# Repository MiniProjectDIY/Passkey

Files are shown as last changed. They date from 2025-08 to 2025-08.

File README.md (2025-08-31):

# Passkey
use your finterprint to send password via virtual keyboard

# ME
Moduleholder: using screw pillar M2\*4*1.5+2.5\*1, M2\*7 screws

Passkey Case: using 4xM2(screw diameter)\*3(Length)\*3.5(outter diameter) screw inserts,M2\*8 screws

# SW
using project:passkey_tune_and_set to :

1.get module sn

2.register your finterprint

3.change module address(do this at last)

using python project PassKey_utils to encrypt your password with your module sn

using project passkey_final_run to run as final code,

remember to change the module address,the macro define and the encrypted password per your own condition.

# HW
using folder production for PCB/SMT process,or handsolder by yourself.


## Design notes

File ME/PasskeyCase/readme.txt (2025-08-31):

using 4*M2(screw diameter)*3(Length)*3.5(outter diameter) screw inserts

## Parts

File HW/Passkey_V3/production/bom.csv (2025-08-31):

Designator | Footprint | Quantity | Value | LCSC Part #
C1, C10, C19, C20, C6, C9 | 0402 | 6 | C_0402_2.2uF_6.3V_X5R
C11, C12, C14, C15, C18, C8 | 0402 | 6 | C_0402_100nF_10V_X7R
C13, C16 | 0402 | 2 | C_0402_15pF_50V_C0G
C17, C2, C5 | 0402 | 3 | C_0402_4.7uF_10V_X5R
C3 | 0402 | 1 | C_0402_1uF_10V_X5R
C7 | 0402 | 1 | C_0402_22nF_50V_X7R
CN1 | CONN-SMD_6P-P1.00_XUNPU_WAFER-SH1.0-6PWB | 1 | WAFER-SH1_0-6PWB | C3029345
D1, D2 | 0402 | 2 | TPESD0402G05V
D3 | 0603 | 1 | NCD0603G1
F1 | 0402 | 1 | BSMD0402L-020
J2 | USB_C_Receptacle_G-Switch_GT-USB-7010ASV | 1 | GT-USB-7010ASV
R10, R11 | 0402 | 2 | R_0402_5.1K_5%
R2, R3 | 0402 | 2 | R_0402_27_5%
R4 | 0402 | 1 | R_0402_200_5%
R5, R6 | 0402 | 2 | R_0402_1K_5%
R7 | 0402 | 1 | R_0402_470_5%
R8, R9 | 0402 | 2 | R_0402_0_5%
SW1 | SW_SPST_B3U-1000P | 1 | B3U-1000P
U1 | USON8-2x3mm-EP0.2x1.6mm | 1 | W25Q16JVUXIQ
U2 | ZW101 | 1 | ~
U4 | QFN-56-1EP_7x7mm_P0.4mm_EP3.2x3.2mm | 1 | RP2040
U5 | SOT-23 | 1 | 662K
Y1 | Crystal_SMD_2520-4Pin_2.5x2.0mm | 1 | X252012MMB4SI-24

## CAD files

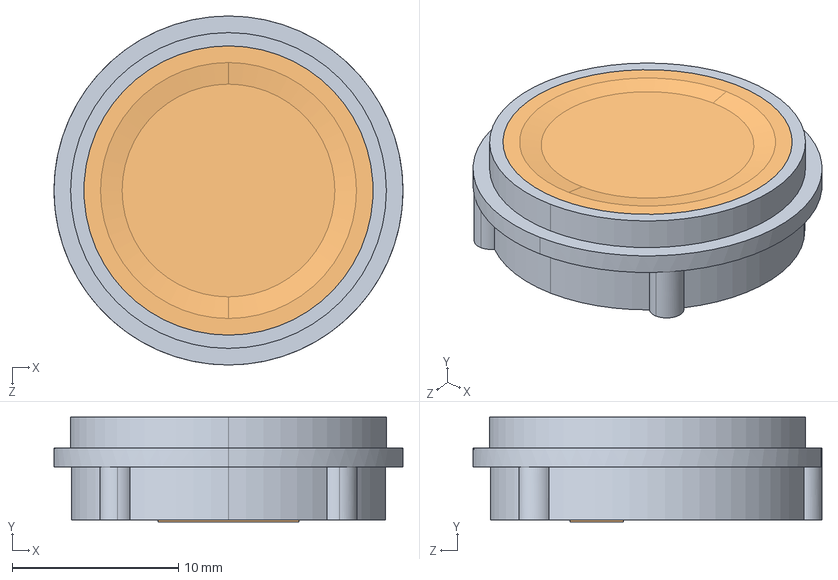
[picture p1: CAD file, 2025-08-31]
Datasheet/ZW101.STEP
21.0 x 6.30 x 21.0 mm
半导体指纹模组外壳
CP-6852 PCB

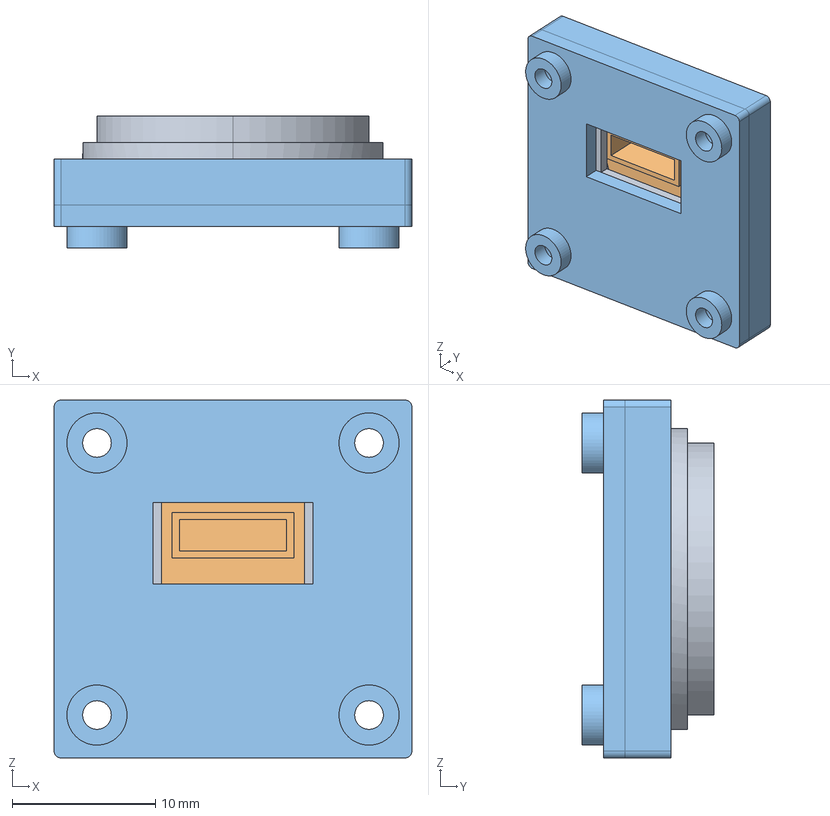
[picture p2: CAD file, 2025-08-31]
ME/ModuleHolder/ZW101_w_holder.step
25.0 x 9.20 x 25.0 mm
mod
CP-6852 PCB
HolderWStub

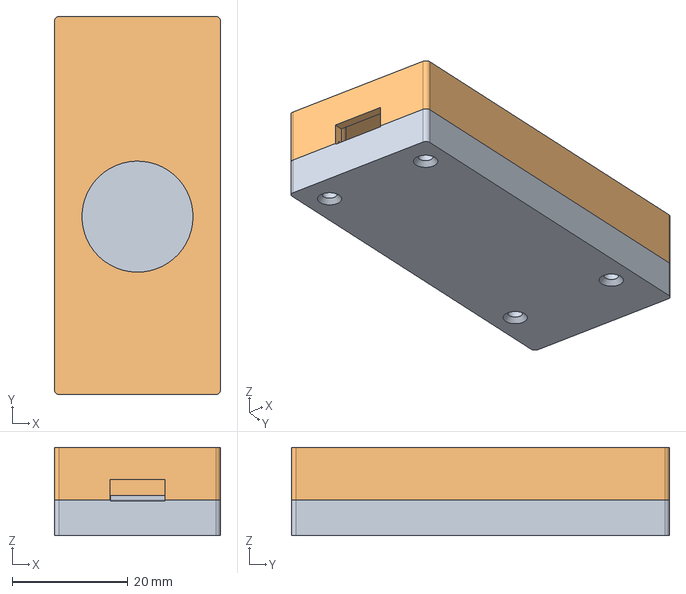
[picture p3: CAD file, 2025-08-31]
ME/PasskeyCase/passkey_v3_case.FCStd
28.7 x 65.3 x 15.3 mm
Bottom
Lid

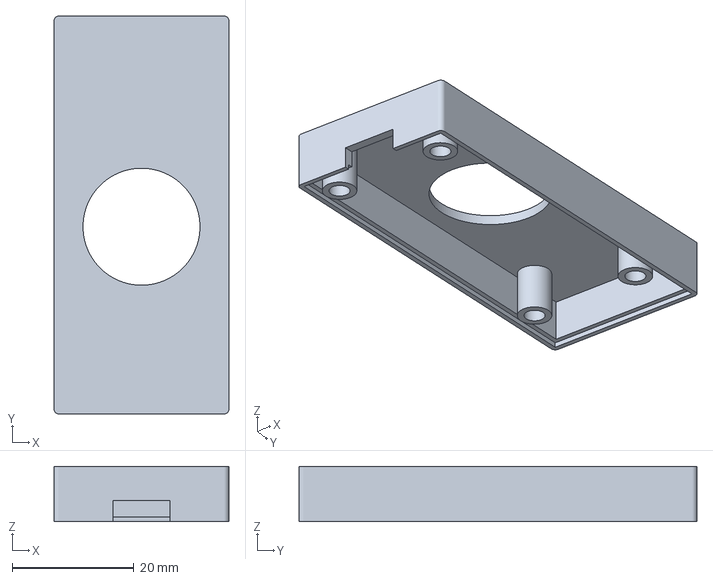
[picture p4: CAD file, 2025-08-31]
ME/PasskeyCase/passkey_v3_case-Lid.3mf
28.7 x 65.3 x 9.10 mm

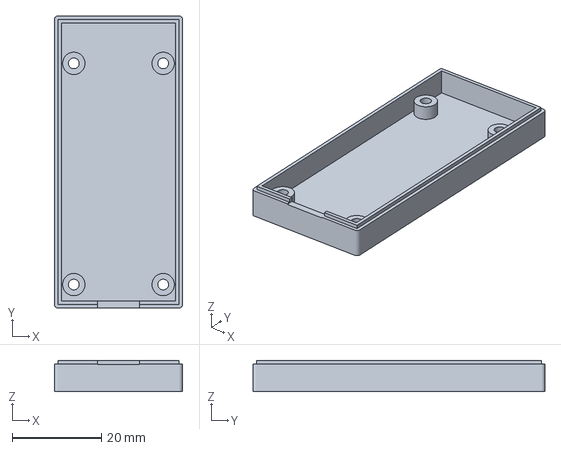
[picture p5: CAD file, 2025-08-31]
ME/PasskeyCase/passkey_v3_case-Bottom.3mf
28.7 x 65.3 x 7.00 mm

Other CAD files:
ME/ModuleHolder/module_holder.FCStd
Datasheet/ZW101.DWG
ME/ModuleHolder/module_holder.3mf

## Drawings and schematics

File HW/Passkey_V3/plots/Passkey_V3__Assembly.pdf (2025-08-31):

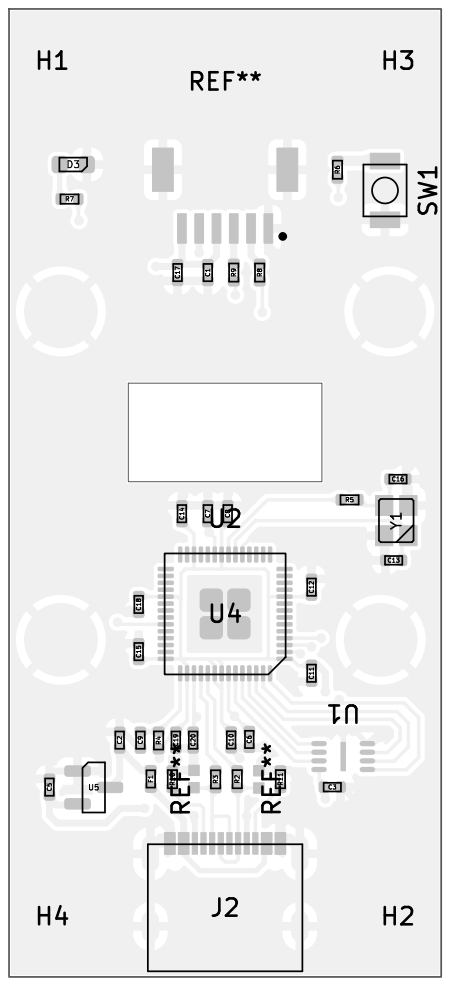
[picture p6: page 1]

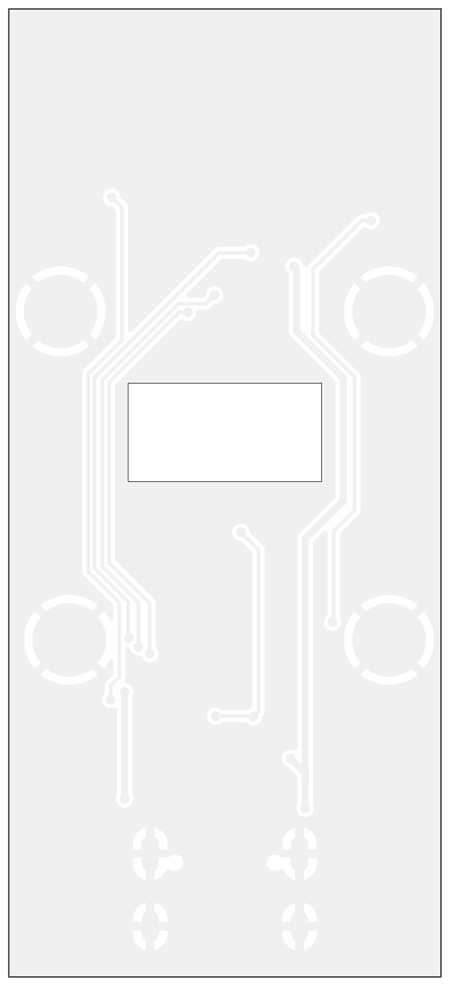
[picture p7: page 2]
D Date: KiCad; E.D.A. 9.0.3 Size: A4; Rev:; Id: /1 Title: File: Passkey_V3.kicad_pcb Sheet: Black; And; White; BOT Board2Pdf:; Black; BOT -; Page 2/2

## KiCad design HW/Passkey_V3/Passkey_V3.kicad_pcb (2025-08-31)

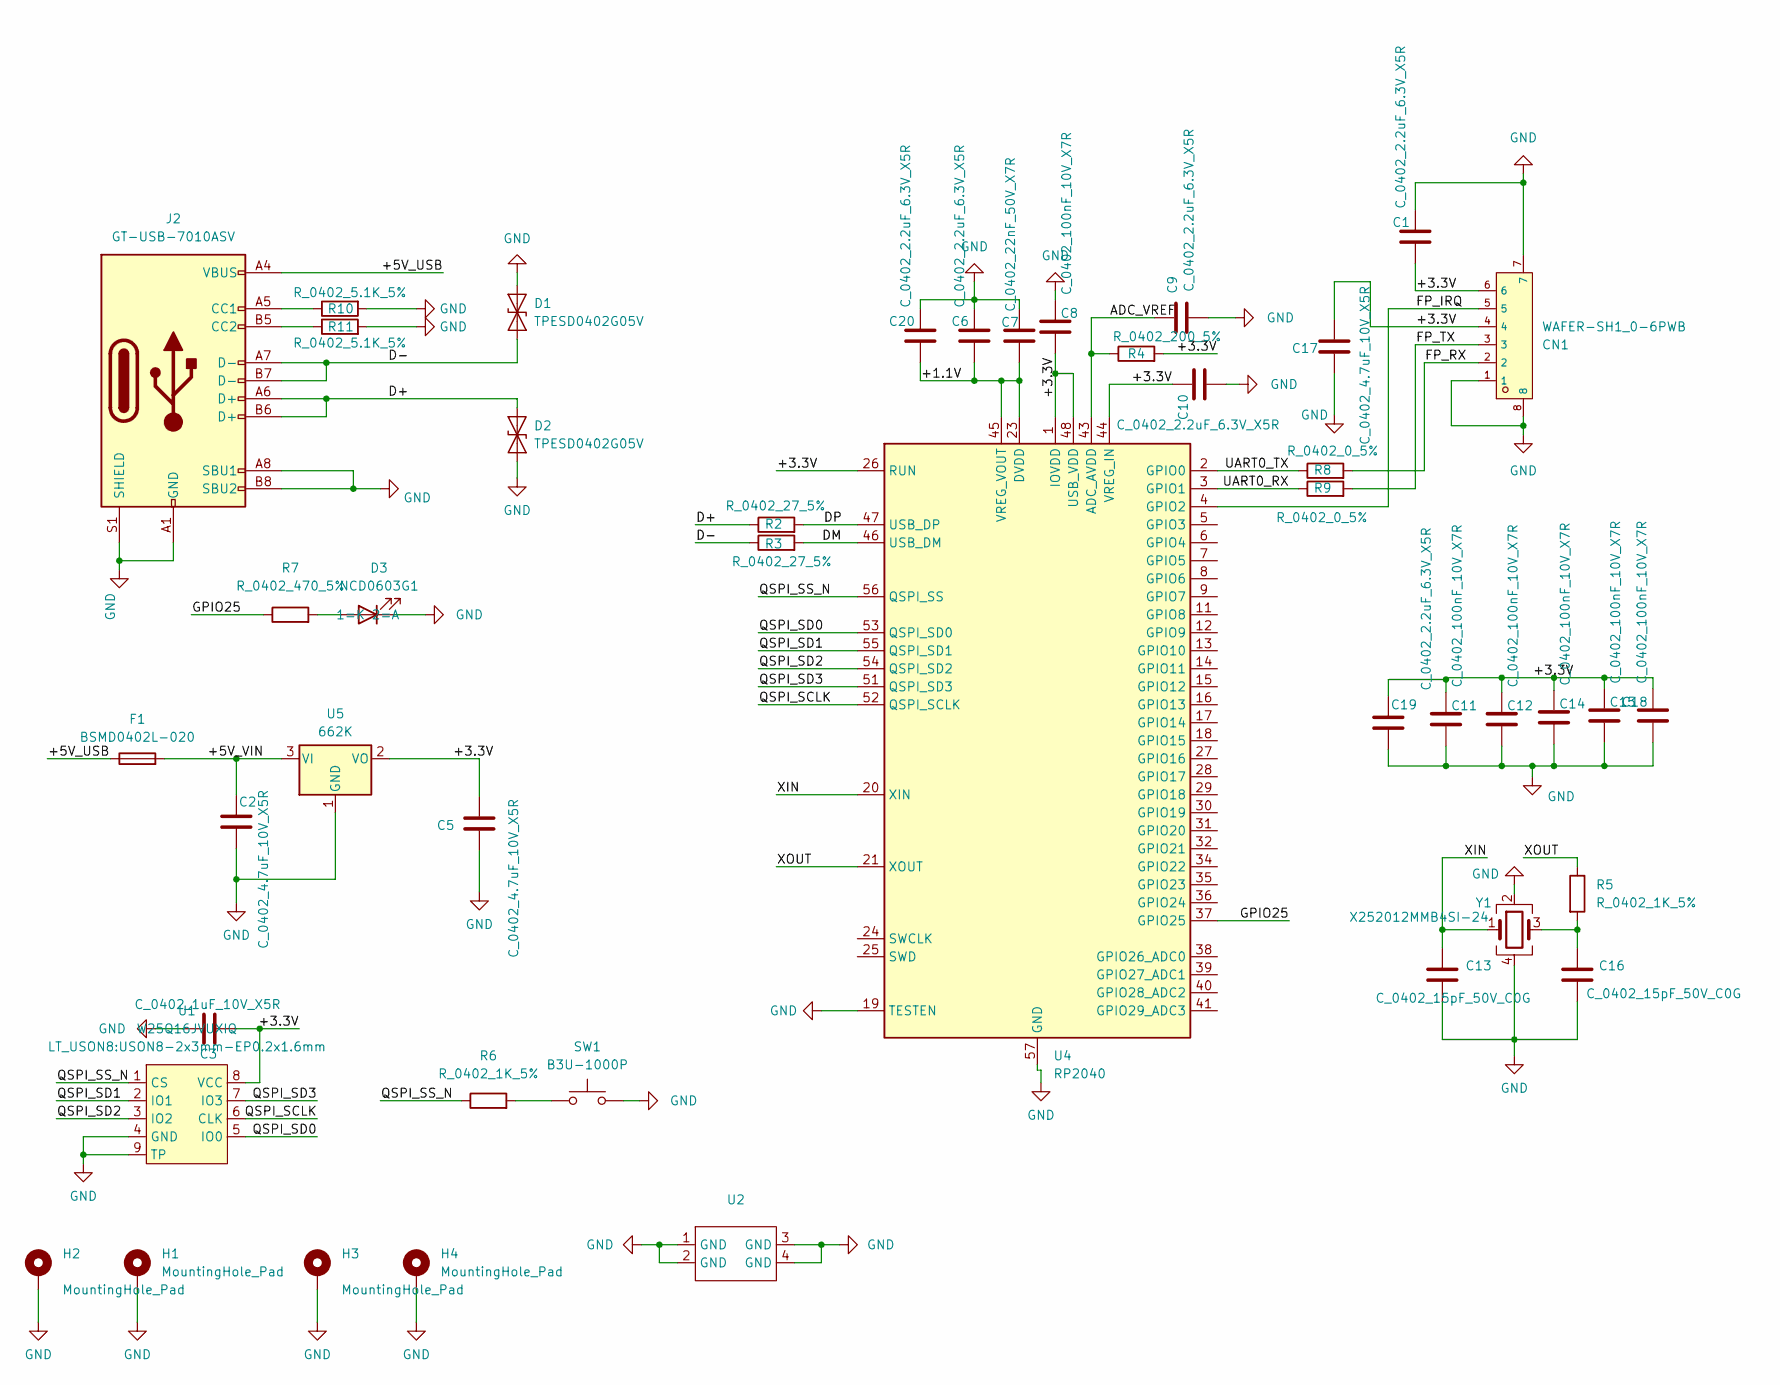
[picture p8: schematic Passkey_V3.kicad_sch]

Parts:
C1, C6, C9, C10, C19, C20: C_0402_2.2uF_6.3V_X5R; C_0402_1005Metric
C2, C5, C17: C_0402_4.7uF_10V_X5R; C_0402_1005Metric
C3: C_0402_1uF_10V_X5R; C_0402_1005Metric
C7: C_0402_22nF_50V_X7R; C_0402_1005Metric
C8, C11, C12, C14, C15, C18: C_0402_100nF_10V_X7R; C_0402_1005Metric
C13, C16: C_0402_15pF_50V_C0G; C_0402_1005Metric
CN1: WAFER-SH1_0-6PWB; CONN-SMD_6P-P1.00_XUNPU_WAFER-SH1.0-6PWB; LCSC C3029345
D1, D2: TPESD0402G05V; D0402-BI
D3: NCD0603G1; LED_0603_1608Metric
F1: BSMD0402L-020; Fuse_0402_1005Metric
H1, H2, H3, H4: MountingHole_Pad; MountingHole_2.2mm_M2_Pad
J2: GT-USB-7010ASV; USB_C_Receptacle_G-Switch_GT-USB-7010ASV
R2, R3: R_0402_27_5%; R_0402_1005Metric
R4: R_0402_200_5%; R_0402_1005Metric
R5, R6: R_0402_1K_5%; R_0402_1005Metric
R7: R_0402_470_5%; R_0402_1005Metric
R8, R9: R_0402_0_5%; R_0402_1005Metric
R10, R11: R_0402_5.1K_5%; R_0402_1005Metric
SW1: B3U-1000P; SW_SPST_B3U-1000P
U1: W25Q16JVUXIQ; USON8-2x3mm-EP0.2x1.6mm
U2: ZW101
U4: RP2040; QFN-56-1EP_7x7mm_P0.4mm_EP3.2x3.2mm
U5: 662K; SOT-23
Y1: X252012MMB4SI-24; Crystal_SMD_2520-4Pin_2.5x2.0mm

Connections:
/+1.1V: C6.2, C7.2, C20.2, U4.23 (DVDD), U4.45 (VREG_VOUT), U4.50 (DVDD)
/+3.3V: C1.2, C3.1, C5.1, C8.2, C10.1, C11.1, C12.1, C14.1, C15.1, C17.1, C18.1, C19.2, CN1.4, CN1.6, R4.2, U1.8 (VCC), U4.1 (IOVDD), U4.10 (IOVDD), U4.22 (IOVDD), U4.26 (RUN), U4.33 (IOVDD), U4.42 (IOVDD), U4.44 (VREG_IN), U4.48 (USB_VDD), U4.49 (IOVDD), U5.2 (VO)
/+5V_USB: F1.1, J2.A4 (VBUS), J2.A9 (VBUS), J2.B4 (VBUS), J2.B9 (VBUS)
/+5V_VIN: C2.1, F1.2, U5.3 (VI)
/ADC_VREF: C9.1, R4.1, U4.43 (ADC_AVDD)
/D+: D2.2 (A2), J2.A6 (D+), J2.B6 (D+), R2.1
/D-: D1.1 (A1), J2.A7 (D-), J2.B7 (D-), R3.1
/DM: R3.2, U4.46 (USB_DM)
/DP: R2.2, U4.47 (USB_DP)
/FP_IRQ: CN1.5, U4.4 (GPIO2)
/FP_RX: CN1.2, R8.2
/FP_TX: CN1.3, R9.2
/GPIO25: R7.1, U4.37 (GPIO25)
/QSPI_SCLK: U1.6 (CLK), U4.52 (QSPI_SCLK)
/QSPI_SD0: U1.5 (IO0), U4.53 (QSPI_SD0)
/QSPI_SD1: U1.2 (IO1), U4.55 (QSPI_SD1)
/QSPI_SD2: U1.3 (IO2), U4.54 (QSPI_SD2)
/QSPI_SD3: U1.7 (IO3), U4.51 (QSPI_SD3)
/QSPI_SS_N: R6.1, U1.1 (CS), U4.56 (QSPI_SS)
/UART0_RX: R9.1, U4.3 (GPIO1)
/UART0_TX: R8.1, U4.2 (GPIO0)
/XIN: C13.1, U4.20 (XIN), Y1.1
/XOUT: R5.1, U4.21 (XOUT)
GND: C1.1, C2.2, C3.2, C5.2, C6.1, C7.1, C8.1, C9.2, C10.2, C11.2, C12.2, C13.2, C14.2, C15.2, C16.2, C17.2, C18.2, C19.1, C20.1, CN1.1, CN1.7, CN1.8, D1.2 (A2), D2.1 (A1), D3.1 (K), H1.1, H2.1, H3.1, H4.1, J2.A1 (GND), J2.A8 (SBU1), J2.A12 (GND), J2.B1 (GND), J2.B8 (SBU2), J2.B12 (GND), J2.S1 (SHIELD), R10.2, R11.2, SW1.2, U1.4 (GND), U1.9 (TP), U2.1 (GND), U2.2 (GND), U2.3 (GND), U2.4 (GND), U4.19 (TESTEN), U4.57 (GND), U5.1 (GND), Y1.2, Y1.4
unnamed: C16.1, R5.2, Y1.3
unnamed: D3.2 (A), R7.2
unnamed: J2.A5 (CC1), R10.1
unnamed: J2.B5 (CC2), R11.1
unnamed: R6.2, SW1.1

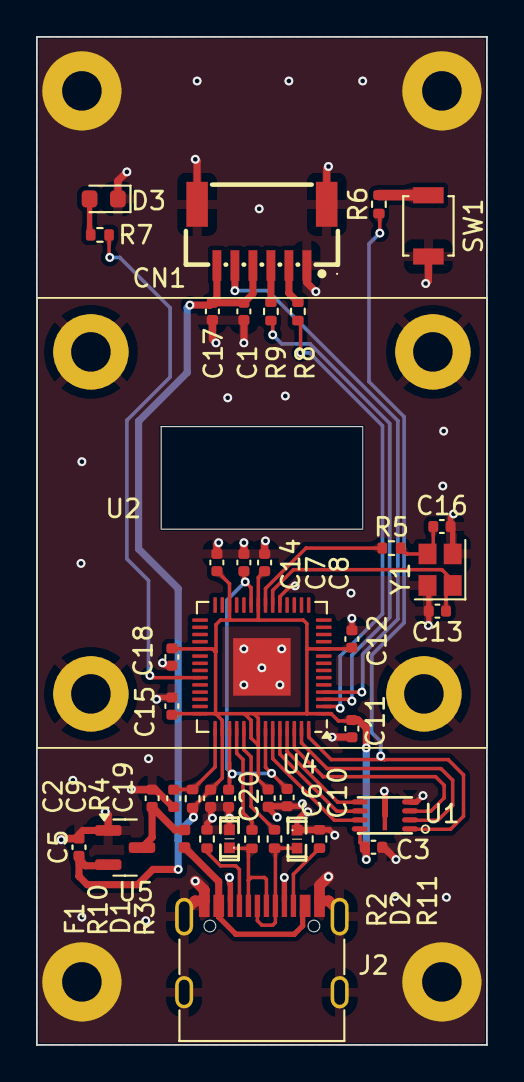
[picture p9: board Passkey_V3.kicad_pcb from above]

Board: 2 copper layers, 25.0 x 56.0 mm, 45 parts (0 on the bottom side), 29 nets.

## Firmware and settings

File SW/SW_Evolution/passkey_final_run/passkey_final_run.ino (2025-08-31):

#include <Keyboard.h>
#include <Base64.h>
#include <AESLib.h>



// 定义UART引脚
#define fpSerial Serial1
#define DebugSerial Serial

//调试模式打开
//#define DEBUG_MODE

// 定义指令包格式
const uint8_t HEADER_HIGH = 0xEF;
const uint8_t HEADER_LOW = 0x01;

// #define DEFAULT_MODULE_ADDR
#define NEW_MODULE_ADDR

//Define module that has factory default addr
#ifdef DEFAULT_MODULE_ADDR
//command 8 will change  module addr from default addr to new addr
const uint32_t DEVICE_ADDRESS = 0xFFFFFFFF;
const uint32_t NEW_DEVICE_ADDRESS = 0x0106E9D3;
#endif

//Define module that has addr changed,set your own addr!
#ifdef NEW_MODULE_ADDR
//command 8 will change revert module addr to default addr
const uint32_t DEVICE_ADDRESS = 0x0106E9D3;
const uint32_t NEW_DEVICE_ADDRESS = 0xFFFFFFFF;
#endif


// 定义指令码
const uint8_t CMD_GET_IMAGE = 0x01;       // 获取图像
const uint8_t CMD_GEN_CHAR = 0x02;        // 生成特征
const uint8_t CMD_MATCH = 0x03;           // 精确比对指纹
const uint8_t CMD_SEARCH = 0x04;          // 搜索指纹
const uint8_t CMD_REG_MODEL = 0x05;       // 合并特征
const uint8_t CMD_STORE_CHAR = 0x06;      // 存储模板
const uint8_t CMD_CLEAR_LIB = 0x0D;       // 清空指纹库
const uint8_t CMD_READ_SYSPARA = 0x0F;    // 读模组基本参数
const uint8_t CMD_READ_CHIPSN = 0x34;     // 读模组序列号
const uint8_t CMD_SET_CHIPPWD = 0x12;     // 设置模组密码
const uint8_t CMD_VERIFY_CHIPPWD = 0x13;  // 验证模组密码
const uint8_t CMD_SET_CHIPADDR = 0x15;    // 设置模组地址
const uint8_t CMD_FACTORY_RESET = 0x3b;   // 恢复出厂设置


// 定义缓冲区ID
uint8_t BUFFER_ID = 0;

// 定义模板存储起始位置
uint16_t PAGE_ID = 0;

// 全局变量
bool isInit = false;

uint8_t module_sn[16];
uint8_t module_pwd[4] = { 'T', '5', '2', 'C' };
uint8_t new_module_addr[4] = { (NEW_DEVICE_ADDRESS >> 24) & 0xFF, (NEW_DEVICE_ADDRESS >> 16) & 0xFF, (NEW_DEVICE_ADDRESS >> 8) & 0xFF, NEW_DEVICE_ADDRESS & 0xFF };
AESLib aesLib;
char encrypted_base64[] = "AAECAwQFBgcICQoLDA0OD4NCHqJqj7j9TmrCwI//X7XRGtsRwZipl4mVmiuGx0Gj";


// 函数声明
void command_use(void);
int read_FP_info(void);
void sendCommand(uint8_t cmd, uint8_t param1 = 0, uint16_t param2 = 0);
void sendCommand1(uint8_t cmd, uint8_t param1, uint16_t param2, uint16_t param3);
bool verifyResponse();
void printResponse(uint8_t* response, uint8_t length);

/*****My declaration start*****/
bool get_module_sn(uint8_t module_sn[16]);
bool set_module_password(uint8_t module_pwd[4]);
bool verify_module_password(uint8_t module_pwd[4]);
bool set_module_address(uint8_t new_module_addr[4]);
bool module_factory_reset(void);
void decrypt_password_base64(const char* encrypted_base64, char* output_buffer, int output_buffer_len, const uint8_t* aes_key, int key_len);
/*****My declaration end*****/

void printHex(uint8_t* data, uint8_t len) {
  for (uint8_t i = 0; i < len; i++) {
    if (data[i] < 0x10) DebugSerial.print('0');
    DebugSerial.print(data[i], HEX);
    DebugSerial.print(' ');
  }
  DebugSerial.println();
}

void setup() {
  // Init the serial port for fingerprint module
  fpSerial.begin(57600);
  // Init the usb virtual keyboard
  Keyboard.begin();
#if defined(DEBUG_MODE)
  DebugSerial.begin(57600);
  DebugSerial.println("Passkey Inited...");
#endif
}

void loop() {
  decrypt_password_and_keyin();
  delay(500);
}

void command_use(void) {
  DebugSerial.println("------------------------------------------");
  DebugSerial.println("command input:");
  DebugSerial.println("\"1\" means \"register fingerprint.\"");
  DebugSerial.println("\"2\" means \"search fingerprint.\"");
  DebugSerial.println("\"3\" means \"clear fingerprint.\"");
  DebugSerial.println("\"4\" means \"display module serial number.\"");
  DebugSerial.println("\"5\" means \"search fingerprint and decrypt test password\"");
  DebugSerial.println("\"6\" means \"set module password(hardcoded)\"");
  DebugSerial.println("\"7\" means \"verify module password(hardcoded)\"");
  DebugSerial.println("\"8\" means \"set module address(hardcoded)\"");
  DebugSerial.println("\"9\" means \"factory reset the module\"");
  DebugSerial.println("------------------------------------------");
}

int run_command(void) {
  // 当串口有数据可读时
  if (DebugSerial.available() > 0) {
    // 读取直到换行符（自动处理回车+换行）
    // defautl timeout after 1s
    String command = DebugSerial.readStringUntil('\n');
    command.trim();  // 去除首尾空白字符（包括换行和回车）

    // 判断命令并执行对应操作
    if (command == "1") {
      //注册指纹
      DebugSerial.println("[INFO] registering...");
      if (register_FP()) {
        DebugSerial.println("FP registration process complete!");
      } else {
        DebugSerial.println("FP registration process fail! Please 'register' again!!!");
      }
    } else if (command == "2") {
      //搜索指纹匹配
      DebugSerial.println("[INFO] searching...");
      if (search_FP()) {
        DebugSerial.println("FP match succeed!");
      } else {
        DebugSerial.println("FP match fail! Please 'search' again!!!");
      }
    } else if (command == "3") {
      //清除模组存储的指纹
      DebugSerial.println("[INFO] clearing...");
      if (clear_all_fingerprint()) {
        DebugSerial.println("FP clear FP all lib succeed!");
      } else {
        DebugSerial.println("FP clear FP all lib fail! Please 'clear' again!!!");
      }
    } else if (command == "4") {
      //读取指纹模组的SN
      DebugSerial.println("[INFO] reading chip SN...");
      if (get_module_sn(module_sn)) {
        DebugSerial.println("Chip SN:");
        for (int i = 0; i < 16; i++) {
          if (module_sn[i] < 0x10) DebugSerial.print("0");
          DebugSerial.print(module_sn[i], HEX);
        }
        DebugSerial.print("\n");
      }
    } else if (command == "5") {
      decrypt_password_and_keyin();
      //读取指纹，输出密码
    } else if (command == "6") {
      if (set_module_password(module_pwd)) {
        DebugSerial.println("password set succeed!");
      } else {
        DebugSerial.println("password set failed!");
      }
    }
    //设置模组密码
    else if (command == "7") {
      if (verify_module_password(module_pwd)) {
        DebugSerial.println("password verify succeed!");
      } else {
        DebugSerial.println("password verify failed!");
      }
    }
    //验证模组密码
    else if (command == "8") {
      if (set_module_address(new_module_addr)) {
        DebugSerial.println("address set succeed!");
      } else {
        DebugSerial.println("address set failed!");
      }
      //修改模组地址
    } else if (command == "9") {
      if (module_factory_reset()) {
        DebugSerial.println("module reset succeed!");
      } else {
        DebugSerial.println("module reset failed!");
      }
      //修改模组地址
    } else {
      // 未知命令处理
      DebugSerial.print("[ERROR] unknown cmd: ");
      DebugSerial.println(command);
    }
  }
  return 0;
}

//读模组基本参数
int read_FP_info(void) {
  uint8_t response[32];
  uint8_t index = 0;
  uint32_t startTime = millis();

  DebugSerial.println("ZW101 FPM info:");
  send_cmd(CMD_READ_SYSPARA);

  // 等待响应包
  while (millis() - startTime < 2000) {
    if (fpSerial.available()) {
      response[index++] = fpSerial.read();
      if (index >= 28) break;
    }
  }

  // 打印响应包
  // printResponse(response, index);

  // 检查确认码
  if (index >= 28 && response[9] == 0x00) {
    uint16_t register_cnt = (uint16_t)(response[10] << 8) | response[11];
    uint16_t fp_temp_size = (uint16_t)(response[12] << 8) | response[13];
    uint16_t fp_lib_size = (uint16_t)(response[14] << 8) | response[15];
    uint16_t score_level = (uint16_t)(response[16] << 8) | response[17];
    uint32_t device_addr = (uint32_t)(response[18] << 24) | (response[19] << 16) | (response[20] << 8) | response[21];
    uint16_t data_pack_size = (uint16_t)(response[22] << 8) | response[23];
    if (0 == data_pack_size) {
      data_pack_size = 32;
    } else if (1 == data_pack_size) {
      data_pack_size = 64;
    } else if (2 == data_pack_size) {
      data_pack_size = 128;
    } else if (3 == data_pack_size) {
      data_pack_size = 256;
    }
    uint16_t baud_set = (uint16_t)(response[24] << 8) | response[25];

    DebugSerial.print("register cnt:");
    DebugSerial.println(register_cnt);
    DebugSerial.print("temp size:0x");
    DebugSerial.println(fp_temp_size, HEX);
    DebugSerial.print("lib size:");
    DebugSerial.println(fp_lib_size);
    DebugSerial.print("level:");
    DebugSerial.println(score_level);
    DebugSerial.print("devece address:0x");
    DebugSerial.println(device_addr, HEX);
    DebugSerial.print("data size:");
    DebugSerial.println(data_pack_size);
    DebugSerial.print("baud:");
    DebugSerial.println(baud_set * 9600);
    return 1;  // 成功
  } else {
    return 0;  // 失败
  }
}



//注册指纹
int register_FP(void) {
  BUFFER_ID = 1;
  while (BUFFER_ID <= 5) {
    // 步骤1：获取图像
    send_cmd(CMD_GET_IMAGE);
    // 等待指纹模组响应
    if (verifyResponse()) {
    } else {
      delay(1000);
      continue;
    }

    // 步骤2：生成特征
    send_cmd2(CMD_GEN_CHAR, BUFFER_ID);
    if (verifyResponse()) {
      BUFFER_ID++;
      DebugSerial.println("Press your finger...");
    } else {
      continue;
    }
  }

  // 步骤3：合并特征
  send_cmd(CMD_REG_MODEL);
  if (verifyResponse()) {

  } else {
    return 0;
  }

  // 步骤4：存储模板
  BUFFER_ID = 1;
  sendCommand(CMD_STORE_CHAR, BUFFER_ID, PAGE_ID);
  if (verifyResponse()) {
  } else {
    return 0;
  }
  PAGE_ID += 1;
  //不+1则再次录入后只会覆盖第一位指纹，而不会新增指纹模板
  return 1;
}

//搜索指纹
int search_FP(void) {
  int serch_cnt = 0;
  BUFFER_ID = 1;
  while (serch_cnt <= 5) {
    // 步骤1：获取图像
    send_cmd(CMD_GET_IMAGE);

    // 等待指纹模组响应
    if (verifyResponse()) {

    } else {
      delay(1000);
      continue;
    }

    // 步骤2：生成特征
    send_cmd2(CMD_GEN_CHAR, BUFFER_ID);
    if (verifyResponse()) {
      break;
    } else {
      serch_cnt++;
      delay(500);
      continue;
    }
  }

  // 步骤3：搜索指纹
  BUFFER_ID = 1;
  sendCommand1(CMD_SEARCH, BUFFER_ID, 1, 1);
  if (verifyResponse()) {
    return 1;
  }
  return 0;
}

//清空指纹库
int clear_all_fingerprint(void) {
  send_cmd(CMD_CLEAR_LIB);
  if (verifyResponse()) {
    return 1;
  }
  return 0;
}

// 发送指令包
void send_cmd(uint8_t cmd) {
  uint8_t packet[12];
  uint16_t length = 3;
  uint16_t checksum = 1 + length + cmd;

  // 构建指令包
  packet[0] = HEADER_HIGH;
  packet[1] = HEADER_LOW;
  packet[2] = (DEVICE_ADDRESS >> 24) & 0xFF;
  packet[3] = (DEVICE_ADDRESS >> 16) & 0xFF;
  packet[4] = (DEVICE_ADDRESS >> 8) & 0xFF;
  packet[5] = DEVICE_ADDRESS & 0xFF;
  packet[6] = 0x01;                  // 包标识：命令包
  packet[7] = (length >> 8) & 0xFF;  // 包长度高字节
  packet[8] = length & 0xFF;         // 包长度低字节
  packet[9] = cmd;

  packet[10] = (checksum >> 8) & 0xFF;
  packet[11] = checksum & 0xFF;

#if defined(DEBUG_MODE)
  DebugSerial.println("send_cmd:");
  printHex(packet, 12);
#endif

  // 发送指令包
  for (int i = 0; i < 12; i++) {
    fpSerial.write(packet[i]);
  }
}
// 发送指令包
void send_cmd2(uint8_t cmd, uint8_t param1) {
  uint8_t packet[13];
  uint16_t length = 4;
  uint16_t checksum = 1 + length + cmd + param1;

  // 构建指令包
  packet[0] = HEADER_HIGH;
  packet[1] = HEADER_LOW;
  packet[2] = (DEVICE_ADDRESS >> 24) & 0xFF;
  packet[3] = (DEVICE_ADDRESS >> 16) & 0xFF;
  packet[4] = (DEVICE_ADDRESS >> 8) & 0xFF;
  packet[5] = DEVICE_ADDRESS & 0xFF;
  packet[6] = 0x01;                  // 包标识：命令包
  packet[7] = (length >> 8) & 0xFF;  // 包长度高字节
  packet[8] = length & 0xFF;         // 包长度低字节
  packet[9] = cmd;
  packet[10] = param1;
  packet[11] = (checksum >> 8) & 0xFF;
  packet[12] = checksum & 0xFF;

#if defined(DEBUG_MODE)
  DebugSerial.println("send_cmd2:");
  printHex(packet, 13);
#endif

  // 发送指令包
  for (int i = 0; i < 13; i++) {
    fpSerial.write(packet[i]);
  }
}

// 发送指令包
void sendCommand(uint8_t cmd, uint8_t param1, uint16_t param2) {
  uint8_t packet[15];
  uint16_t length = 6;
  uint16_t checksum = 1 + length + cmd + param1 + (param2 >> 8) + (param2 & 0xFF);

  // 构建指令包
  packet[0] = HEADER_HIGH;
  packet[1] = HEADER_LOW;
  packet[2] = (DEVICE_ADDRESS >> 24) & 0xFF;
  packet[3] = (DEVICE_ADDRESS >> 16) & 0xFF;
  packet[4] = (DEVICE_ADDRESS >> 8) & 0xFF;
  packet[5] = DEVICE_ADDRESS & 0xFF;
  packet[6] = 0x01;                  // 包标识：命令包
  packet[7] = (length >> 8) & 0xFF;  // 包长度高字节
  packet[8] = length & 0xFF;         // 包长度低字节
  packet[9] = cmd;
  packet[10] = param1;
  packet[11] = (param2 >> 8) & 0xFF;
  packet[12] = param2 & 0xFF;
  packet[13] = (checksum >> 8) & 0xFF;
  packet[14] = checksum & 0xFF;

#if defined(DEBUG_MODE)
  DebugSerial.println("send:");
  printHex(packet, (2 + 4 + 3 + length));
#endif

  // 发送指令包
  for (int i = 0; i < (2 + 4 + 3 + length); i++) {
    fpSerial.write(packet[i]);
  }
}

// 发送指令包
void sendCommand1(uint8_t cmd, uint8_t param1, uint16_t param2, uint16_t param3) {
  uint8_t packet[17];
  uint16_t length = 8;
  uint16_t checksum = 1 + length + cmd + param1 + (param2 >> 8) + (param2 & 0xFF) + (param3 >> 8) + (param3 & 0xFF);

  // 构建指令包
  packet[0] = HEADER_HIGH;
  packet[1] = HEADER_LOW;
  packet[2] = (DEVICE_ADDRESS >> 24) & 0xFF;
  packet[3] = (DEVICE_ADDRESS >> 16) & 0xFF;
  packet[4] = (DEVICE_ADDRESS >> 8) & 0xFF;
  packet[5] = DEVICE_ADDRESS & 0xFF;
  packet[6] = 0x01;                  // 包标识：命令包
  packet[7] = (length >> 8) & 0xFF;  // 包长度高字节
  packet[8] = length & 0xFF;         // 包长度低字节
  packet[9] = cmd;
  packet[10] = param1;
  packet[11] = (param2 >> 8) & 0xFF;
  packet[12] = param2 & 0xFF;
  packet[13] = (param3 >> 8) & 0xFF;
  packet[14] = param3 & 0xFF;
  packet[15] = (checksum >> 8) & 0xFF;
  packet[16] = checksum & 0xFF;

#if defined(DEBUG_MODE)
  DebugSerial.println("send:");
  printHex(packet, (2 + 4 + 3 + length));
#endif

  // 发送指令包
  for (int i = 0; i < 2 + 4 + 3 + length; i++) {
    fpSerial.write(packet[i]);
  }
}



// 接收响应包
bool verifyResponse() {
  uint8_t response[50];
  uint8_t index = 0;
  uint32_t startTime = millis();

  // 等待响应包
  while (millis() - startTime < 500) {
    if (fpSerial.available()) {
      response[index++] = fpSerial.read();
    }
  }

  // 打印响应包
#if defined(DEBUG_MODE)
  printResponse(response, index);

#endif

  // 检查确认码
  if (index >= 12 && response[9] == 0x00) {
    return true;  // 成功
  } else {
    return false;  // 失败
  }
}

// 打印响应包
void printResponse(uint8_t* response, uint8_t length) {
  DebugSerial.print("Response:");
  for (int i = 0; i < length; i++) {
    if (response[i] < 0x10) DebugSerial.print('0');
    DebugSerial.print(response[i], HEX);
    DebugSerial.print(" ");
  }
  DebugSerial.println();
}


/*******custom command send to send single 4 bytes command******/
void sendCommand2(uint8_t cmd, uint8_t param1[4]) {
  uint8_t packet[16];
  uint16_t length = 7;
  uint16_t checksum = 1 + length + cmd + param1[0] + param1[1] + param1[2] + param1[3];

  // 构建指令包
  packet[0] = HEADER_HIGH;
  packet[1] = HEADER_LOW;
  packet[2] = (DEVICE_ADDRESS >> 24) & 0xFF;
  packet[3] = (DEVICE_ADDRESS >> 16) & 0xFF;
  packet[4] = (DEVICE_ADDRESS >> 8) & 0xFF;
  packet[5] = DEVICE_ADDRESS & 0xFF;
  packet[6] = 0x01;                  // 包标识：命令包
  packet[7] = (length >> 8) & 0xFF;  // 包长度高字节
  packet[8] = length & 0xFF;         // 包长度低字节
  packet[9] = cmd;
  packet[10] = param1[0];
  packet[11] = param1[1];
  packet[12] = param1[2];
  packet[13] = param1[3];
  packet[14] = (checksum >> 8) & 0xFF;
  packet[15] = checksum & 0xFF;

#if defined(DEBUG_MODE)
  DebugSerial.println("sendCommand2:");
  printHex(packet, 16);
#endif

  // 发送指令包
  for (int i = 0; i < 16; i++) {
    fpSerial.write(packet[i]);
  }
}
/*******custom command send to send single 4 bytes command******/


/*****get serial number for module****/
bool get_module_sn(uint8_t module_sn[16]) {
  uint8_t response[50];
  uint8_t index = 0;
  uint32_t startTime = millis();
  send_cmd2(CMD_READ_CHIPSN, 0);
  // should receive 44 bytes response
  while (millis() - startTime < 2000) {
    if (fpSerial.available()) {
      response[index++] = fpSerial.read();
      if (index >= 44) break;
    }
  }
  if (index < 40) return false;
  for (int i = 0; i < 16; i++) {
    module_sn[i] = response[10 + i];  // 从第11个字节开始（下标10）
  }
  return true;
}
/*****get serial number for module****/


/*****set module password****/
/*******没什么用，密码掉电就丢失，别用这个功能*******/
bool set_module_password(uint8_t module_pwd[4]) {
  sendCommand2(CMD_SET_CHIPPWD, module_pwd);
  return verifyResponse();
}
/*****set module password****/



/*****verify module password****/
bool verify_module_password(uint8_t module_pwd[4]) {
  sendCommand2(CMD_VERIFY_CHIPPWD, module_pwd);
  return verifyResponse();
}
/*****verify module password****/



/*****set module address****/
/******一定要记住修改后的addr，否则连factory reset都无法进行*******/
bool set_module_address(uint8_t new_module_addr[4]) {
  sendCommand2(CMD_SET_CHIPADDR, new_module_addr);
  return verifyResponse();
}
/*****set module address****/

/*****module  factory reset****/
/*******factory reset并不修改addr，而且addr不对时也无法factory reset********/
bool module_factory_reset(void) {
  send_cmd(CMD_FACTORY_RESET);
  return verifyResponse();
}
/*****module factory reset****/

/*****decrypt password with aes****/
/********ChatGPT写的，我也不懂*********/
void decrypt_password_base64(const char* encrypted_base64, char* output_buffer, int output_buffer_len, const uint8_t* aes_key, int key_len) {
  int base64_len = strlen(encrypted_base64);
  char base64_buf[base64_len + 1];
  strcpy(base64_buf, encrypted_base64);

  int decoded_len = Base64.decodedLength(base64_buf, base64_len);
  byte decoded[decoded_len];
  Base64.decode((char*)decoded, base64_buf, base64_len);

  if (decoded_len <= 16) {  // IV + ciphertext 长度不合理
    output_buffer[0] = '\0';
    return;
  }

  byte iv[16];
  memcpy(iv, decoded, 16);  // 前16字节是IV

  byte* ciphertext = decoded + 16;  // 密文指针
  int ciphertext_len = decoded_len - 16;

  int decrypted_len = aesLib.decrypt(ciphertext, ciphertext_len, (byte*)output_buffer, aes_key, key_len, iv);

  if (decrypted_len <= 0) {
    output_buffer[0] = '\0';
    return;
  }

  // 去除PKCS7填充
  byte pad_len = output_buffer[decrypted_len - 1];
  if (pad_len > 0 && pad_len <= 16) {
    decrypted_len -= pad_len;
  }

  if (decrypted_len < output_buffer_len) {
    output_buffer[decrypted_len] = '\0';
  } else {
    output_buffer[output_buffer_len - 1] = '\0';
  }
}

/*****decrypt password with aes****/



/*****test decrypt password with module_sn****/
void decrypt_password_and_keyin() {
  char decrypted[64];
  if (search_FP()) {
    if (get_module_sn(module_sn)) {
      decrypt_password_base64(encrypted_base64, decrypted, sizeof(decrypted), module_sn, 16);
      Keyboard.print(decrypted);
      Keyboard.write(KEY_RETURN);
    }
  }
}
/*****test decrypt password with module_sn****/
